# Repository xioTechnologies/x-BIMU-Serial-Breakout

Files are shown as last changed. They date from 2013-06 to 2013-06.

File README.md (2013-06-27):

x-BIMU-Serial-Breakout
======================

x-BIMU serial breakout board

* FTDI compatible 6-way male header (x-BIMU UART inputs are 5 V tolerant)
* Pull-down resistor on CTS input means that hardware flow-control connections are not necessary
* 3.1 mm diameter mounting holes (position = 31 mm x 27 mm)
* All components are SMD and on top side only and no copper on bottom side allow PCB bottom to be adhered to surfaces without risk of damage

Version history
---------------

* **v1.1** CTS pull-down removed.  Bypass voltage regulator jumper
* **v1.0** Initial design

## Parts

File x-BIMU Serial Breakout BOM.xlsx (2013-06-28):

Name | Qty | Device
U1 | 1 | MIC5319-3.3YD5 (http://uk.rs-online.com/web/p/low-dropout-voltage-regulators/7275226/)
C1 | 1 | 4u7, 0603
C2 | 1 | 100n, 0603
C3 | 1 | 10u, 0603
H1 | 1 | 6-way SMD R/A header (https://www.sparkfun.com/products/9015)
x-BIMU | 1 | 10-way SMD socket (x2) (https://www.sparkfun.com/products/10030)

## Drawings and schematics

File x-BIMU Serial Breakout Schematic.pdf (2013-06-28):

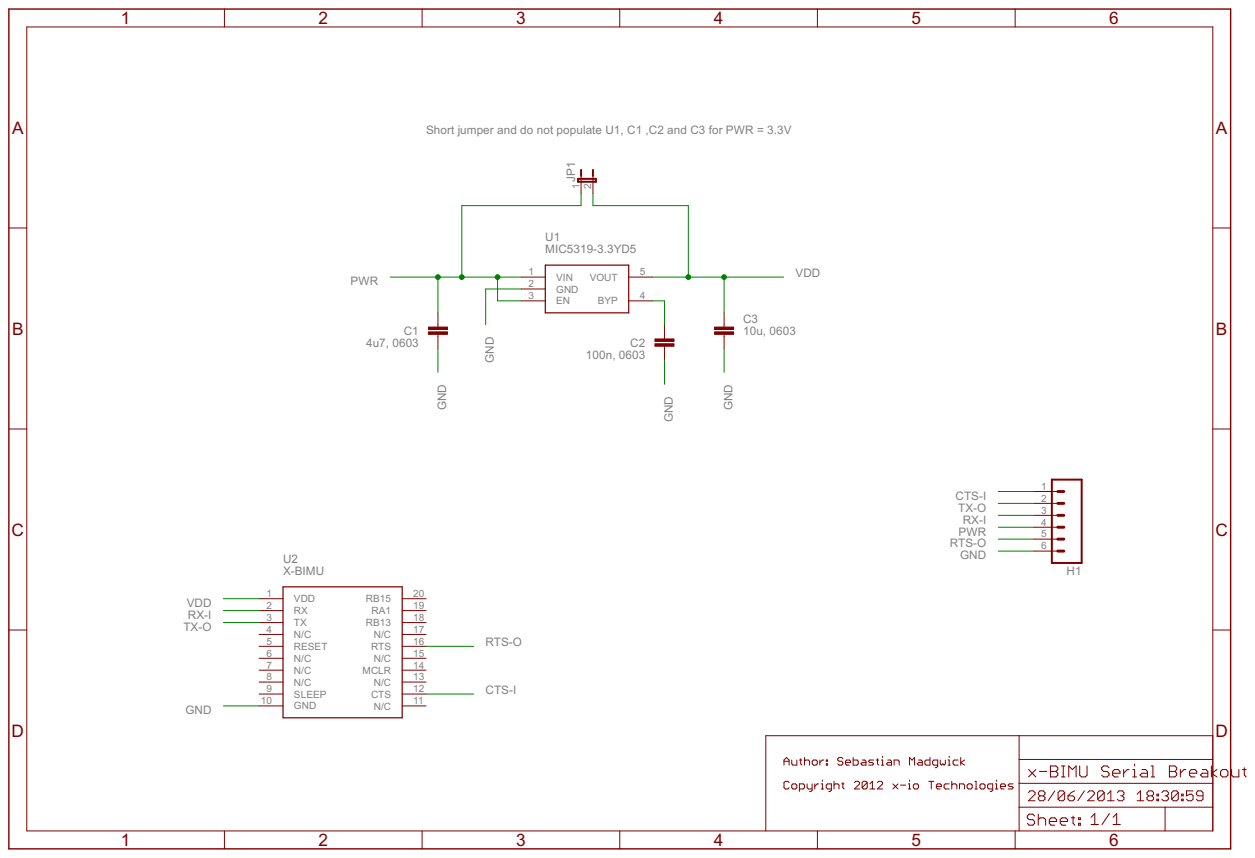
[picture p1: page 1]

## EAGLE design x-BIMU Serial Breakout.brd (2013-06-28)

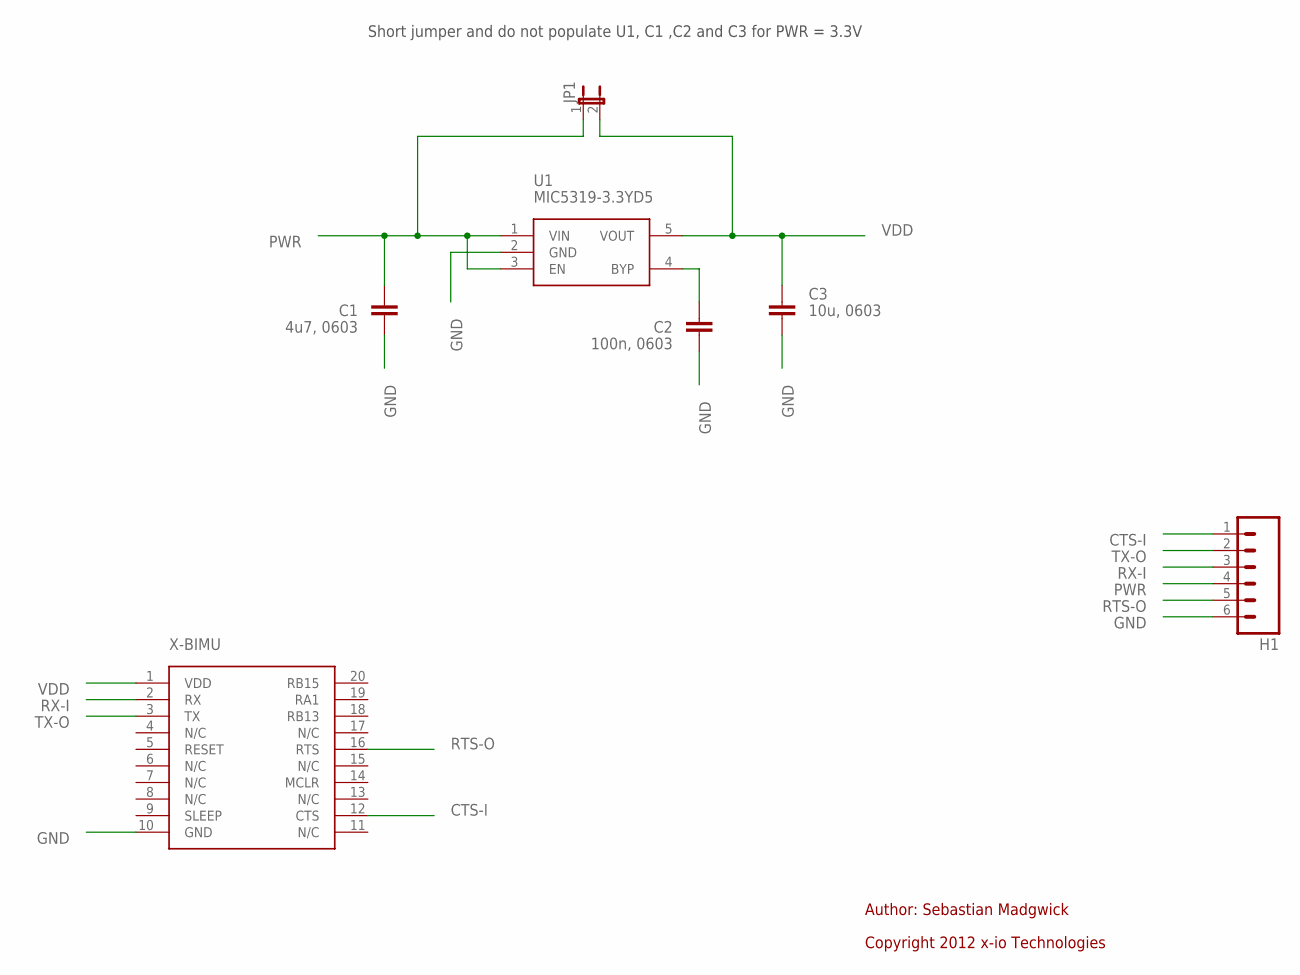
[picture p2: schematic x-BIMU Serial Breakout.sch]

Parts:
C1: 4u7, 0603; 0402-CAP
C2: 100n, 0603; 0402-CAP
C3: 10u, 0603; 0402-CAP
H1: M06SMD; 1X06-SMD
JP1: JUMPER-2SMD-NO; SJ_2S-NO
U1: MIC5319-3.3YD5; SOT23-5
U2: X-BIMU; X-BIMU_SMD

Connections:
CTS-I: H1.1, U2.12 (CTS)
GND: C1.2, C2.2, C3.2, H1.6, U1.2 (GND), U2.10 (GND)
unnamed: C2.1, U1.4 (BYP)
PWR: C1.1, H1.4, JP1.1, U1.1 (VIN), U1.3 (EN)
RTS-O: H1.5, U2.16 (RTS)
RX-I: H1.3, U2.2 (RX)
TX-O: H1.2, U2.3 (TX)
VDD: C3.1, JP1.2, U1.5 (VOUT), U2.1 (VDD)

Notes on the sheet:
Author: Sebastian Madgwick
Copyright 2012 x-io Technologies
Short jumper and do not populate U1, C1 ,C2 and C3 for PWR = 3.3V

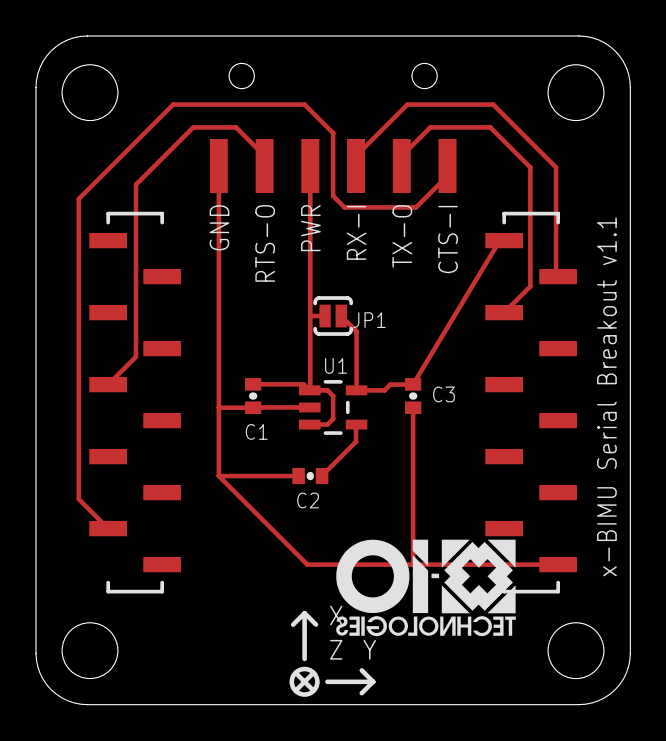
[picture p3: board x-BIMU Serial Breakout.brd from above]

Board: 2 copper layers, 33.0 x 37.1 mm, 9 parts (1 on the bottom side), 8 nets.

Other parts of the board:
U$1: X-IO_TECHNOLOGIES_LOGO_10MM_BOTTOM
U$2: OSHW_LOGO_6MM_BOTTOM

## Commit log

2013-04-07 1k CTS pull-down to account for internal pull-up
    [x-BIMU Serial Breakout.brd, x-BIMU Serial Breakout.sch]
2013-06-27 Remove CTS pull-down. Add regulator bypass jumper
    [x-BIMU Serial Breakout.brd, x-BIMU Serial Breakout.sch]
2013-06-28 Include BOM
    [x-BIMU Serial Breakout BOM.xlsx, x-BIMU Serial Breakout.brd, x-BIMU Serial Breakout.sch]
